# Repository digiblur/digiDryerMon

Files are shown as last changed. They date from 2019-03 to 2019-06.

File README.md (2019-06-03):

# digiDryerMon
ESP8266 based washer/dryer current monitoring via a split core current transformer with ESPHome.  Pull Requests are welcome!  Please open an issue if you have any support needs.

Video Demostration and Setup - https://www.youtube.com/watch?v=1tqJkw5f0iA

### Parts List
[Split Core Current Transformer](https://amzn.to/2XDcnoX)  
[Wemos D1 Mini](https://amzn.to/2Z44jNS)  
[10µF Capacitor](https://amzn.to/2VFhGC6)  
[10k Resistors](https://amzn.to/2ErWhWi)  
[Preformed Jumpers](https://amzn.to/2Ha3bCs)  
[Screw terminals](https://amzn.to/2WiJoZF)
[Breadboard](https://amzn.to/2HbdINP)  

[Alternative NodeMCU 8266](https://amzn.to/2Eo3Ahu)  
[Alternative NodeMCU 8285](https://amzn.to/2TdNMIo)

### Sample Home Assistant Automation
https://www.digiblur.com/2018/11/smart-laundry-notifications-with-sonoff.html

### Wiring Diagram
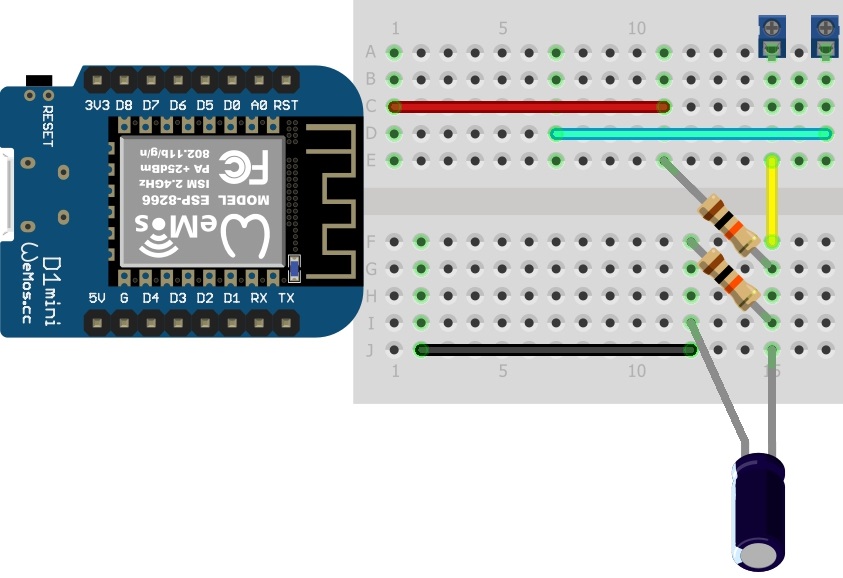
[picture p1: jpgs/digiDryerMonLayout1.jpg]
Wiring Diagram

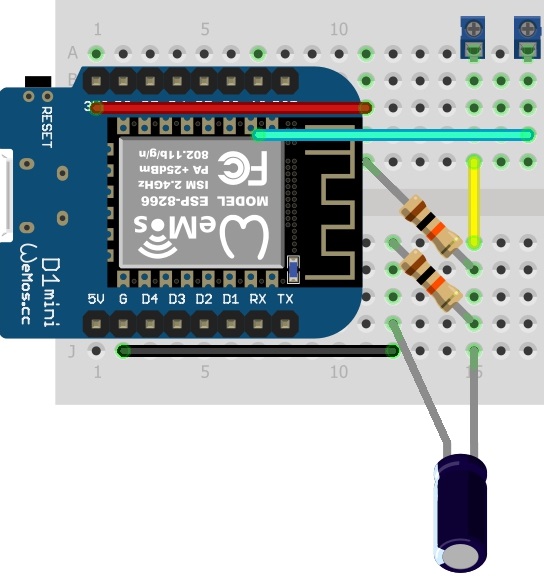
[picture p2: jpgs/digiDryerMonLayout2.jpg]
Wiring Diagram2

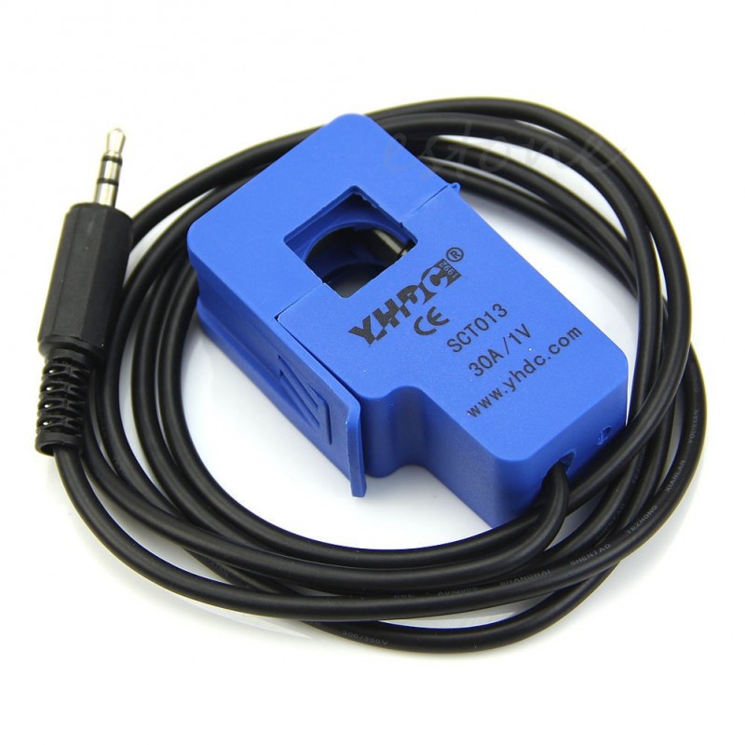
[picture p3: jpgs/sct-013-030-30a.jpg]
SCT 30A/1V


The original Arduino IDE version sketch and ESPHome Custom Component versions have been moved to subfolders for historic purposes.

### Sample Home Assistant Config (Deprecated Arduino IDE Sketch Config)

Video Demostration and Setup - https://www.youtube.com/watch?v=1tqJkw5f0iA

```YAML
sensor:
  - platform: mqtt
    name: "Dryer Current"
    state_topic: "digiDryerMon-4A443E/SCT"
    unit_of_measurement : "A"
    icon: mdi:flash-circle
    availability_topic: "digiDryerMon-4A443E/LWT"
    payload_available: "Online"
    payload_not_available: "Offline"

  - platform: mqtt
    name: "DryerMon Signal"
    state_topic: "digiDryerMon-4A443E/RSSI"
    unit_of_measurement: "dBm"
    availability_topic: "digiDryerMon-4A443E/LWT"
    payload_available: "Online"
    payload_not_available: "Offline"   

  - platform: mqtt
    name: "DryerMon Status"
    state_topic: "digiDryerMon-4A443E/BUILD"
    availability_topic: "digiDryerMon-4A443E/LWT"
    payload_available: "Online"
    payload_not_available: "Offline"
```

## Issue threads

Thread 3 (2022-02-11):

Perfboard version.

RevelRob, 2022-02-11:
First off, this is awesome. I got it to work with the breadboard and jumpers; however, as an idiot, I am trying to figure out how to recreate your perfboard version. Is there any way to possibly attach a picture of the Wemos attached to the perfboard version you made and possibly a picture of both sides of the created perfboard? Hopefully I have an "Ah Ha!" moment after seeing it.

Thanks so much for what you have contributed to the community! It is so appreciated.

RevelRob, 2022-02-14:
After watching the video again, I heard you say that you use jumper wires to connect the board with the Wemos D1 Mini.
I wanted something cleaner; so I made it as follows:
I grabbed a Perf board set from Amazon and threw something together using some of the preformed jumpers, capacitor, resistors and a 3.5mm female jack connector that I got a long time ago:
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

I got this USB drive awhile ago and it came with this neat magnetic case and some foam to hold the drive:
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

I cut the foam piece a bit, tossed the board into the case, and drilled out some holes (One day, I will buy a 3D printer... one day):
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

The finished product:
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

Hooked up to the dryer:
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

I actually almost gave up because the plug goes in through the bottom of the non-removable back panel. I started pulling apart the dryer bit by bit where I was afraid I wouldn't be able to put it back together. I was at the point where I would have to remove the drum to get to where I could see the inside of the back panel. I decided it was time to turn back. Right before closing up this top panel; I thought, no way were these wires going to be pulling enough amperage to read anything. I was happily incorrect.

She works!
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

I added a "cooling" notification; but it looks like the dryer dips to "cooling" amperage a few times before the final 10 min mark:
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

Anyways. Thanks for this! I was my first time playing with an ESP development board besides flashing some sonoff devices. After this, I bought a bunch of Wemos and some ESP32's and have been amazed at the amount of things that can be done.

digiblur, 2022-02-14:
Just happened to see this thread...Nice pics and execution of the device!  Thanks for sharing things.  Sounds like some of the various pieces of fun for trying to determine if the washing machine is running or not.  They are all different for sure.

Closed 2022-02-14.

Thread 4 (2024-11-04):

CT Clamp comes with 3 cables, White, Red and Black, which ones should I use?

distante, 2024-11-04:
Hi, I hope you can help me understand this.

The CT Clamps, including the one from your link, comes with a TRS connector, so it has 3 cables, I am trying to figure it out how should I connect it.

I had not opened the CT cable it self but bought a TRS female connector and for now I put some cables to connect it to the breadboard for testing
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

Should I let one pin floating? If so, which one?

Thank you!

distante, 2024-11-05:
Someone send me the datasheeat: https://statics3.seeedstudio.com/assets/file/bazaar/product/101990028-SCT-013-030-Datasheet.pdf

The tip and the ring are what we need to use. so I will just check which cables are those. If they are like regular audio cables, it is probably the white and black ones.

distante, 2024-11-05:
Just to shine about the cables in case someone else needs the info.

I did a test with a voltmeter in AC mode and looks like, even when the specs says that the signal come thru tip and sleeve, I only get voltage changes if I connect tip and ring. I did this with two CT Clamps from different stores (but both from Ali Express) and they both just reported voltage changes when using Tip and Ring.

Closed 2024-11-05.

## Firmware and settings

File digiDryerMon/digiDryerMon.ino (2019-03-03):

// =-=-=-=-=-=-=-=-=-=-=-=-=-=-=-=-=-=-=-=-=-=-=-=-=-=-=-=-=-=-=-=-=-=-=-=-= //
#include <ESP8266WiFi.h>
#include <Ticker.h>
#include <AsyncMqttClient.h>  // https://github.com/marvinroger/async-mqtt-client (requires: https://github.com/me-no-dev/ESPAsyncTCP)
#include <WiFiUdp.h>
#include <ArduinoOTA.h>
#include "config.h"           // rename sample_config.h and edit any values needed
#include <ESP8266WiFi.h>
#include <ESP8266WebServer.h>
#include <ESP8266HTTPUpdateServer.h>
#include <EmonLib.h>

// =-=-=-=-=-=-=-=-=-=-=-=-=-=-=-=-=-=-=-=-=-=-=-=-=-=-=-=-=-=-= //
// Input Pins                                                    //
// =-=-=-=-=-=-=-=-=-=-=-=-=-=-=-=-=-=-=-=-=-=-=-=-=-=-=-=-=-=-= //
#define currentPin      A0
// =-=-=-=-=-=-=-=-=-=-=-=-=-=-=-=-=-=-=-=-=-=-=-=-=-=-=-=-=-=-= //
// Output Pins                                                   //
// =-=-=-=-=-=-=-=-=-=-=-=-=-=-=-=-=-=-=-=-=-=-=-=-=-=-=-=-=-=-= //
#define intLED1Pin  D4  // D4 Wemos Mini D1 and NodeMCU
// =-=-=-=-=-=-=-=-=-=-=-=-=-=-=-=-=-=-=-=-=-=-=-=-=-=-=-=-=-=-= //
// Verb/State Conversions                                        //
// =-=-=-=-=-=-=-=-=-=-=-=-=-=-=-=-=-=-=-=-=-=-=-=-=-=-=-=-=-=-= //
#define LEDon       LOW
#define LEDoff      HIGH
// =-=-=-=-=-=-=-=-=-=-=-=-=-=-=-=-=-=-=-=-=-=-=-=-=-=-=-=-=-=-= //
// Poll Times / Misc                                             //
// =-=-=-=-=-=-=-=-=-=-=-=-=-=-=-=-=-=-=-=-=-=-=-=-=-=-=-=-=-=-= //
#define sctPoll        10  // 10 seconds or more is recommended 
#define rePushPoll     300 // push all sensor data every xx seconds - helpful if retain isn't used as this sketch only pushes data if a sensor changes.
#define mqttQOSLevel   2
#define emonCalcIrms   15000  // current calibration settings
#define emonCurrent    30     // current calibration settings
// =-=-=-=-=-=-=-=-=-=-=-=-=-=-=-=-=-=-=-=-=-=-=-=-=-=-=-=-=-=-= //
// VARS Begin                                                    //
// =-=-=-=-=-=-=-=-=-=-=-=-=-=-=-=-=-=-=-=-=-=-=-=-=-=-=-=-=-=-= //
char mcuHostName[64]; 
char sctTopic[96];    
char lwtTopic[96];  
char buildTopic[96];
char rssiTopic[96];
char sSCTcur[5];
char sSCTcurTemp[5]; 
unsigned long wifiLoopNow = 0;
int mqttTryCount = 0;

float sctDiff = 0.1;  // difference in current to trigger a MQTT publish
// -+-+
float sctCur = 99;
float sctNewCur;
// -+-+
bool initBoot = true;

ESP8266WebServer httpServer(80);
ESP8266HTTPUpdateServer httpUpdater;
#ifdef DEBUGTELNET
  WiFiServer telnetServer(23);
  WiFiClient telnetClient;
#endif

AsyncMqttClient mqttClient;
Ticker mqttReconnectTimer;
Ticker sctTick;
Ticker rePushTick;
Ticker led1FlipTick;
Ticker wifiReconnectTimer;

WiFiEventHandler wifiConnectHandler;
WiFiEventHandler wifiDisconnectHandler;
EnergyMonitor emon1;

// =-=-=-=-=-=-=-=-=-=-=-=-=-=-=-=-=-=-=-=-=-=-=-=-=-=-=-=-=-=-= //
// connectToWifi                                                 //
// =-=-=-=-=-=-=-=-=-=-=-=-=-=-=-=-=-=-=-=-=-=-=-=-=-=-=-=-=-=-= //
void connectToWifi() {
  debugLn(F("WIFI: Attempting to Connect."));
  wifiLoopNow = millis(); // mark start time
  WiFi.mode(WIFI_STA);
  WiFi.hostname(mcuHostName);
  WiFi.begin(wifiSSID, wifiPass);
  delay(10);  
  // toggle on board LED as WiFi comes up
  digitalWrite(intLED1Pin, LEDoff);
  while (WiFi.status() != WL_CONNECTED) {
     digitalWrite(intLED1Pin, !(digitalRead(intLED1Pin)));  //Invert Current State of LED  
     delay(70);
     digitalWrite(intLED1Pin, !(digitalRead(intLED1Pin)));   
     delay(45);
     if (millis() > wifiLoopNow + 30000) {  // WiFi Stuck?  Reboot ESP and start over...
       debugLn(F("ESP: WiFi Failed. Restarting ESP."));
       delay(100);
       ESP.restart();      
     }
  }
  digitalWrite(intLED1Pin, LEDoff);
}
// =-=-=-=-=-=-=-=-=-=-=-=-=-=-=-=-=-=-=-=-=-=-=-=-=-=-=-=-=-=-= //
// onWifiConnect                                                 //
// =-=-=-=-=-=-=-=-=-=-=-=-=-=-=-=-=-=-=-=-=-=-=-=-=-=-=-=-=-=-= //
void onWifiConnect(const WiFiEventStationModeGotIP& event) {
  long rssi = WiFi.RSSI();
  debugLn(String(F("WIFI: Connected - IP: ")) + WiFi.localIP().toString() + " - RSSI: " + String(rssi) );
  connectToMqtt();
}
// =-=-=-=-=-=-=-=-=-=-=-=-=-=-=-=-=-=-=-=-=-=-=-=-=-=-=-=-=-=-= //
// onWifiDisconnect                                              //
// =-=-=-=-=-=-=-=-=-=-=-=-=-=-=-=-=-=-=-=-=-=-=-=-=-=-=-=-=-=-= //
void onWifiDisconnect(const WiFiEventStationModeDisconnected& event) {
  debugLn(F("WIFI: Disconnected."));
  mqttReconnectTimer.detach(); // don't reconnect to MQTT while reconnecting to Wi-Fi
  wifiReconnectTimer.once(2, connectToWifi);
}
// =-=-=-=-=-=-=-=-=-=-=-=-=-=-=-=-=-=-=-=-=-=-=-=-=-=-=-=-=-=-= //
// connectToMqtt                                                 //
// =-=-=-=-=-=-=-=-=-=-=-=-=-=-=-=-=-=-=-=-=-=-=-=-=-=-=-=-=-=-= //
void connectToMqtt() {
  debugLn(String(F("MQTT: Attempting connection to ")) + String(mqttHost) + " as " + mcuHostName);
  mqttClient.connect();
  mqttTryCount++;
  if (mqttTryCount > 15) {
    debugLn(F("ESP: MQTT Failed too many times. Restarting ESP."));
    delay(100);
    ESP.restart();      
  }  
}
// =-=-=-=-=-=-=-=-=-=-=-=-=-=-=-=-=-=-=-=-=-=-=-=-=-=-=-=-=-=-= //
bool checkBoundSensor(float newValue, float prevValue, float maxDiff) {
  return newValue < prevValue - maxDiff || newValue > prevValue + maxDiff;
}
// =-=-=-=-=-=-=-=-=-=-=-=-=-=-=-=-=-=-=-=-=-=-=-=-=-=-=-=-=-=-= //
// Check Sensor                                                  //
// =-=-=-=-=-=-=-=-=-=-=-=-=-=-=-=-=-=-=-=-=-=-=-=-=-=-=-=-=-=-= //
void checkSCT()
{
  debugLn(F("SCT: Read"));
  digitalWrite(intLED1Pin, LEDon);
  float sctNewCur = emon1.calcIrms(emonCalcIrms);
  digitalWrite(intLED1Pin, LEDoff);  
  dtostrf(sctNewCur, 2, 2, sSCTcurTemp);
  debugLn(String(F("SCT: Results - Current: "))+ sSCTcurTemp);
  // check curr difference - update the status?
  if (checkBoundSensor(sctNewCur, sctCur, sctDiff)) {
    sctCur = sctNewCur;
    dtostrf(sctCur, 2, 2, sSCTcur);
    debugLn(F("SCT: Publish new value via MQTT"));
    digitalWrite(intLED1Pin, LEDon);
    mqttClient.publish(sctTopic, mqttQOSLevel, false, String(sSCTcur).c_str());   
    digitalWrite(intLED1Pin, LEDoff);     
  }
}  

// =-=-=-=-=-=-=-=-=-=-=-=-=-=-=-=-=-=-=-=-=-=-=-=-=-=-=-=-=-=-= //
// onMqttConnect                                                 //
// =-=-=-=-=-=-=-=-=-=-=-=-=-=-=-=-=-=-=-=-=-=-=-=-=-=-=-=-=-=-= //
void onMqttConnect(bool sessionPresent) {
  debugLn(F("MQTT: Connected"));
  mqttTryCount = 0;
  mqttClient.publish(lwtTopic, 2, true, mqttBirth);
  // Setup Sensor Polling
  sctTick.attach(sctPoll, checkSCT);
  rePushTick.attach(rePushPoll, rePushVals);
}

// =-=-=-=-=-=-=-=-=-=-=-=-=-=-=-=-=-=-=-=-=-=-=-=-=-=-=-=-=-=-= //
// onMqttDisconnect                                              //
// =-=-=-=-=-=-=-=-=-=-=-=-=-=-=-=-=-=-=-=-=-=-=-=-=-=-=-=-=-=-= //
void onMqttDisconnect(AsyncMqttClientDisconnectReason reason) {
  debugLn(F("MQTT: Disconnected."));
  if (WiFi.isConnected()) {
    mqttReconnectTimer.once(2, connectToMqtt);
  }
  // if MQTT is disconnected stop polling sensors
  sctTick.detach();
  rePushTick.detach();
}

void flipLED1() {
  digitalWrite(intLED1Pin, !(digitalRead(intLED1Pin)));  //Invert Current State of LED  
}

const char *getDeviceID() {
  char *identifier = new char[30];
  os_strcpy(identifier, hostName);
  strcat_P(identifier, PSTR("-"));

  char cidBuf[7];
  sprintf(cidBuf, "%06X", ESP.getChipId());
  os_strcat(identifier, cidBuf);

  return identifier;
}

// =-=-=-=-=-=-=-=-=-=-=-=-=-=-=-=-=-=-=-=-=-=-=-=-=-=-=-=-=-=-= //
// ESP Setup                                                     //
// =-=-=-=-=-=-=-=-=-=-=-=-=-=-=-=-=-=-=-=-=-=-=-=-=-=-=-=-=-=-= //
void setup() {
  #ifdef DEBUGSERIAL
    Serial.begin(115200);
    while(!Serial) {} // Wait
    Serial.println();
  #endif  
  debugLn(String(F("digiDryerMon - Build: ")) + F(__DATE__) + " " +  F(__TIME__));
  // build hostname with last 6 of MACID
  os_strcpy(mcuHostName, getDeviceID());

  // ~~~~ Set MQTT Topics
  sprintf_P(lwtTopic, PSTR("%s/LWT"), mcuHostName);
  sprintf_P(sctTopic, PSTR("%s/SCT"), mcuHostName);
  sprintf_P(rssiTopic, PSTR("%s/RSSI"), mcuHostName);
  sprintf_P(buildTopic, PSTR("%s/BUILD"), mcuHostName);
 
  // ~~~~ Set PIN Modes
  pinMode(intLED1Pin,OUTPUT); 
  pinMode(currentPin,INPUT);

  // ~~~~ Setup emonlib
  emon1.current(currentPin, emonCurrent);
  emon1.calcIrms(emonCalcIrms);

  delay(10);  

  wifiConnectHandler = WiFi.onStationModeGotIP(onWifiConnect);

  // setup MQTT
  mqttClient.setWill(lwtTopic,2,true,mqttDeath,0);
  mqttClient.setCredentials(mqttUser,mqttPass);
  mqttClient.onConnect(onMqttConnect);
  mqttClient.onDisconnect(onMqttDisconnect);
  mqttClient.setServer(mqttHost, mqttPort);
  mqttClient.setMaxTopicLength(512);
  mqttClient.setClientId(mcuHostName);

  connectToWifi();
  wifiDisconnectHandler = WiFi.onStationModeDisconnected(onWifiDisconnect);
  #ifdef DEBUGTELNET
    // Setup telnet server for remote debug output
    telnetServer.setNoDelay(true);
    telnetServer.begin();
    debugLn(String(F("Telnet: Started on port 23 - IP:")) + WiFi.localIP().toString());
  #endif

  // OTA Flash Sets
  ArduinoOTA.setPort(OTAport);
  ArduinoOTA.setHostname(mcuHostName);
  ArduinoOTA.setPassword((const char *)OTApassword);

  ArduinoOTA.onStart([]() {
    Serial.println("Starting");
  });
  ArduinoOTA.onEnd([]() {
    Serial.println("\nEnd");
  });
  ArduinoOTA.onProgress([](unsigned int progress, unsigned int total) {
    Serial.printf("Progress: %u%%\r", (progress / (total / 100)));
  });
  ArduinoOTA.onError([](ota_error_t error) {
    Serial.printf("Error[%u]: ", error);
    if (error == OTA_AUTH_ERROR) Serial.println("Auth Failed");
    else if (error == OTA_BEGIN_ERROR) Serial.println("Begin Failed");
    else if (error == OTA_CONNECT_ERROR) Serial.println("Connect Failed");
    else if (error == OTA_RECEIVE_ERROR) Serial.println("Receive Failed");
    else if (error == OTA_END_ERROR) Serial.println("End Failed");
  });
  ArduinoOTA.begin();

  // Setup HTTP Flash Page
  httpUpdater.setup(&httpServer, "/flash", update_username, update_password);
  httpServer.on("/restart", []() {
    debugLn(F("HTTP: Restart request received."));
    httpServer.sendHeader("Access-Control-Allow-Origin", "*");
    httpServer.send(200, "text/plain", "Restart command sent to ESP Chip..." );
    delay(100);
    ESP.restart();
  });
  
  httpServer.begin();
  debugLn(F("ESP: Boot completed - Starting main loop"));
}
// =-=-=-=-=-=-=-=-=-=-=-=-=-=-=-=-=-=-=-=-=-=-=-=-=-=-=-=-=-=-= //
// rePushVals                                                    //
// =-=-=-=-=-=-=-=-=-=-=-=-=-=-=-=-=-=-=-=-=-=-=-=-=-=-=-=-=-=-= //
void rePushVals() {
    debugLn(F("ESP: RePushingVals to MQTT"));
    mqttClient.publish(sctTopic, mqttQOSLevel, false, String(sSCTcurTemp).c_str());      
    mqttClient.publish(rssiTopic, mqttQOSLevel, false, String(WiFi.RSSI()).c_str()); 
    mqttClient.publish(buildTopic, mqttQOSLevel, false, String(String(F("digiDryerMon - Build: ")) + F(__DATE__) + " " +  F(__TIME__) + " - " + WiFi.localIP().toString()).c_str()); 
}

// =-=-=-=-=-=-=-=-=-=-=-=-=-=-=-=-=-=-=-=-=-=-=-=-=-=-=-=-=-=-= //
// Telnet                                                        //
// =-=-=-=-=-=-=-=-=-=-=-=-=-=-=-=-=-=-=-=-=-=-=-=-=-=-=-=-=-=-= //
#ifdef DEBUGTELNET
void handleTelnetClient()
{ 
  if (telnetServer.hasClient())
  {
    // client is connected
    if (!telnetClient || !telnetClient.connected())
    {
      if (telnetClient)
        telnetClient.stop();                   // client disconnected
      telnetClient = telnetServer.available(); // ready for new client
    }
    else
    {
      telnetServer.available().stop(); // have client, block new connections
    }
  }
  // Handle client input from telnet connection.
  if (telnetClient && telnetClient.connected() && telnetClient.available())
  {
    // client input processing
    while (telnetClient.available())
    {
      // Read data from telnet just to clear out the buffer
      telnetClient.read();
    }
  }
}
#endif

// =-=-=-=-=-=-=-=-=-=-=-=-=-=-=-=-=-=-=-=-=-=-=-=-=-=-=-=-=-=-= //
// Serial and Telnet Log Handler                                 //
// =-=-=-=-=-=-=-=-=-=-=-=-=-=-=-=-=-=-=-=-=-=-=-=-=-=-=-=-=-=-= //
void debugLn(String debugText)
{ 
  String debugTimeText = "[+" + String(float(millis()) / 1000, 3) + "s] " + debugText;
  #ifdef DEBUGSERIAL
    Serial.println(debugTimeText);
    Serial.flush();
  #endif
  #ifdef DEBUGTELNET
    if (telnetClient.connected())
    {
      debugTimeText += "\r\n";
      const size_t len = debugTimeText.length();
      const char *buffer = debugTimeText.c_str();
      telnetClient.write(buffer, len);
      handleTelnetClient();
    }
  #endif
}
// =-=-=-=-=-=-=-=-=-=-=-=-=-=-=-=-=-=-=-=-=-=-=-=-=-=-=-=-=-=-= //
// ESP Loop                                                      //
// =-=-=-=-=-=-=-=-=-=-=-=-=-=-=-=-=-=-=-=-=-=-=-=-=-=-=-=-=-=-= //
void loop() {
  ArduinoOTA.handle();
  httpServer.handleClient();
  #ifdef DEBUGTELNET
    handleTelnetClient();
  #endif
  if (initBoot) { // on first loop pull sensors
    delay(2000);  // hold up before first pull, had exception issues in mqtt connect on early pulls on some sensor types
    initBoot = false;
    if (WiFi.isConnected() && mqttClient.connected()) {
      checkSCT();
      delay(20);
      mqttClient.publish(rssiTopic, mqttQOSLevel, false, String(WiFi.RSSI()).c_str()); 
      mqttClient.publish(buildTopic, mqttQOSLevel, false, String(String(F("digiDryerMon - Build: ")) + F(__DATE__) + " " +  F(__TIME__) + " - " + WiFi.localIP().toString()).c_str()); 
      debugLn(String(F("MQTT: digiDryerMon - Build: ")) + F(__DATE__) + " " +  F(__TIME__) + " - " + WiFi.localIP().toString());
    } 
  }
} 

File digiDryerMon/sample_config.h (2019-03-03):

/************ WIFI and MQTT INFORMATION (CHANGE THESE FOR YOUR SETUP) ******************/
#define hostName "digiDryerMon"  

#define wifiSSID "Your SSID"
#define wifiPass "Your Password"

#define mqttHost "192.168.1.x" // mqtt IP/name
#define mqttPort 1883
#define mqttUser "mqtt username"
#define mqttPass "mqtt password"

#define mqttBirth "Online"
#define mqttDeath "Offline"

/******* HTTP /flash page ID/pass **********/
const char* update_username = "admin";
const char* update_password = "OTAdigi"; // change this to a password you want to use when you upload via HTTP

/******* Debug **************/
#define DEBUGSERIAL
#define DEBUGTELNET  // Open a read-only telnet debug port

/******* OTA **************/
int OTAport = 8266;
#define OTApassword "OTAdigi" // change/uncomment this to a password you want to use when you upload OTA

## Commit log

2019-03-03 Add jpg layouts
    [digiDryerMonLayout.fzz]
2019-03-05 Move jpgs to subfolder
    [digiDryerMonLayout.fzz]
2019-06-01 Add delta filter; Cleanup lambdas a bit
2019-06-03 CT Clamp Changes
2021-12-03 Fixed MDI Icon
    Changed icon to mdi_lightning-bolt-circle as flash-circle is deprecated.
